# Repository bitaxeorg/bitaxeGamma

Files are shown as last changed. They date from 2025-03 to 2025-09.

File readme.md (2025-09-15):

```
Open Source is Intrinsic to Bitcoin
```
# The bitaxeGamma
bitaxe is a fully open source Bitcoin ASIC miner aimed at decentralizing mining. bitaxeGamma is the 5th major revision of the bitaxe that now includes the BM1370 ASIC from the Antminer S21 Pro

bitaxeUltra assembled

## Goals
- **Easy**: Just plug it in and mine Bitcoin over WiFi. No external computer needed.
- **Practical**: low cost, low noise, low power, low maintenance. You can run this at home.
- **ASIC Power**: High efficiency and hashrate, based on the latest and greatest Application Specific Integrated Circuits.
- **Versatile**: Mine to any StratumV1 pool, Lottery mine, Solo mine, Or hack it to do whatever you want.
- **Bitcoin Ethos**: Fully open source, permissionless and decentralized to support the worldwide freedom money.

## ASIC
At the heart of the bitaxeGamma is a BM1370 Bitcoin mining ASIC from the Antminer S21 Pro from Bitmain. It's not open source.

- Bitmain claims the BM1370 has 15 J/TH efficiency. We can get pretty close to that with the BitaxeGamma
- The Antminer S21 Pro has a nominal hashrate of 234 TH/s. There are 3 hashboards with 65 chips each, for a total of 195 chips. The bitaxeGamma has a single one of these chips. That means _about_ 1.2 TH/s per bitaxeGamma. Initial testing looks good!
- The BM1370 is brand new and isn't available individually yet. The best place to get these chips is right out of a S21 Pro.
- The BM1370 has a different footprint and pinout from the BM1368, BM1366, BM1397 and BM1387 in previous bitaxe.

## Current Status
- BitaxeGamma 600 is working well and has been released!
- In addition to higher hashrate, the Gamma also uses more power. Please pay attemtion to hash frequency and voltage settings as it's much easier to overheat, especially when using the stock heatsink and fan.
- BM1370 firmware support has been added to [esp-miner](https://github.com/skot/esp-miner)
- Be sure to check the [HW issues](https://github.com/skot/bitaxe/issues) for known bugs, reworks and errata.
- This is an _advanced_ build! You can do it, but if you're not looking for a project, it might be best to buy one pre-assembled from one of the [many sellers](https://bitaxe.org/legit.html). Check [Skot's method](assembly.md) of hand assembling PCBs.

## PCB Hardware
This repo contains all of the design files for the PCB. [KiCAD](https://www.kicad.org/) software is used. There is a BOM file for all of the components that get soldered to the PCB. 

- Order PCBs from your favorite PCB shop, like [JLCPCB](https://jlcpcb.com), [SeeedStudio](https://www.seeedstudio.com/fusion_pcb.html), or [PCBWay](https://www.pcbway.com)
    - Gerbers are in the `Manufacturing Files` dir. PCBs are 4-layer, 6mil trace/space and 0.3mm hole compatible. 1oz outer / 0.5oz inner layer thickness works well.
    - Make sure to order stencils too. These are the "paste" layers in the gerbers folder. one for top and one for bottom.
- All PCB parts except the ASIC are available from [DigiKey](https://www.digikey.com/en/products) and others. You can find Digikey part numbers on the DK tab of the BOM

## Extra Hardware
There are a few other hardware components that are needed for a complete bitaxe.

- **Heatsink**
	- [40x40mm heatsink and 5V fan](https://www.aliexpress.com/item/2251832861666365.html) from a random AliExpress seller. The fans are crap, but the heatsinks are good.  
- **Fan**
	- You **must** have active cooling on the bitaxe. The heatsink alone is not enough.
	- The Bitaxe has a connector for a 4pin, 5V PWM fan. 40mm square, 20mm thick fans work nicely with the suggested heatsink. Make sure to get a 5V fan! 12V spin, but slowly overheating your Bitaxe..
	- Upgrade your fan with the [Noctua NF-A4x10](https://noctua.at/en/nf-a4x10-5v-pwm) 5V 4-Pin fan for a much more pleasant experience.
- **Thermal compound**
	- Use a good quality thermal compound between the heatsink and ASIC. [Thermal Grizzly Kryonaut](https://www.amazon.com/Thermal-Grizzly-Kryonaut-Grease-Paste/dp/B011F7W3LU) has been known to work well.  
- **Display**
	- Supports 0.91" SSD1306-based I2C OLED Module. [Example Amazon seller](https://www.amazon.com/gp/product/B08ZY4YBHL). Make sure to get the male pins to interface with the Bitaxe PCB. 
- **Power Supply**
	- **5V DC Only!** Anything else will damage the Bitaxe. Be careful and double-check your power supply is 5V. Many other voltage power supplies use the same connector.
	- The power supply needs to supply in excess of 4A (20W) and not drop below 5V. Often times you have to use a power supply rated for 25-30W to get this!
 		- The [Meanwell GST60A05-P1J](https://www.digikey.com/en/products/detail/mean-well-usa-inc/GST60A05-P1J/7703709) at 30 Watts is the cadillac of 5V PSUs and is working well with the Gamma.  
	- The bitaxe uses a 5.5x2.1mm, center-positive barrel jack. 5.5x2.5mm plugs have been known to work.
- **Stand**
	- The PCB has corner mounting holes. You're going to want a stand to mount your Bitaxe. Many excellent 3D printed designs are available.

## Firmware
- The [ESP-Miner](https://github.com/skot/ESP-Miner) has initial support for the BM1370 ASIC. Improvements are ongoing.

### ESP32 Programming Requirements
- As of the bitaxeUltra, all ESP32 programming is done through a USB-C cable and connector on the bitaxe. See [ESP-Miner](https://github.com/skot/ESP-Miner) for more details.

## More Information
- Project page at [bitaxe.org](https://bitaxe.org)
- [Open Source Miners United](discord.gg/osmu) Discord chat
- [building.md](building.md) for PCB ordering tips
- [assembly.md](assembly.md) for assembly tips

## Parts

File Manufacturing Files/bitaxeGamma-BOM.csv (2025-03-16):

Qty | Reference | Value | PARTNO | DK | LCSC
1 | C6 | 4700pF | GRM155R71E472KA01D | 490-1309-1-ND
1 | C9 | 2200pF | GRM155R61H222KA01D | 490-8257-1-ND
1 | C10 | 4.7uF | GRM155R61A475MEAAD | 490-14306-1-ND
1 | C11 | 1000pF | CC0805KRX7R9BB102 | 311-1127-1-ND
1 | C13 | 100pF | 885012005013 | 732-7431-1-ND
1 | C50 | 470pF | CL05B471KB5NNNC | 1276-1566-1-ND
24 | C1 C5 C7 C21 C22 C23 C26 C27 C28 C30 C31 C32 C33 C34 C35 C36 C39 C40 C41 C42 C44 C45 C46 C48 | 1uF | EMK105BJ105MV-F | 587-5514-1-ND
3 | C14 C15 C16 | 22uF | GRM21BR61A226ME44L | 490-10746-1-ND
5 | C17 C18 C19 C20 C43 | 100uF | CL31A107MQHNNNE | 1276-1782-1-ND
2 | C2 C24 | 10uF | CL21A106KOQNNNE | 1276-1096-1-ND
3 | C3 C4 C51 | 47uF | CL32A476KOJNNNE | 1276-3376-1-ND
10 | C8 C12 C25 C29 C37 C38 C47 C49 C52 C53 | 0.1uF | CL05A104KO5NNNC | 1276-1234-1-ND
1 | J1 | 54-00164 | 54-00164 | 839-54-00164CT-ND | C431534
1 | J5 | USB_C_Receptacle_USB2.0 | USB4105-GF-A | 2073-USB4105-GF-ACT-ND
1 | J6 | Conn_01x04 | 0470531000 | WM4330-ND
1 | J7 | Conn_01x04
1 | L1 | 300nH | SLC1175-301MEC
1 | R1 | 8.25k | RC0402FR-078K25L | 311-8.25KLRCT-ND
1 | R5 | 14.7k | RC0402FR-0714K7L | YAG2984CT-ND
1 | R6 | 0 | RC0402JR-070RL | 311-0.0JRCT-ND
1 | R8 | 3.74k | RC0402FR-073K74L | 311-3.74KLRCT-ND
1 | R9 | 11.8k | RC0402FR-0711K8L | YAG2958CT-ND
1 | R10 | 68.1k | RC0402FR-0768K1L | YAG3213CT-ND
1 | R11 | 10 | RC0402FR-0710RL | 311-10.0LRCT-ND
1 | R12 | 1 | CSR1206FT1R00 | CSR1206FT1R00CT-ND
1 | R19 | 1k | RC0402FR-071KL | 311-1.00KLRCT-ND
1 | R21 | 20k | RC0402FR-0720KL | 311-20.0KLRCT-ND
1 | R24 | 5.6k | RC0402FR-135K6L | 13-RC0402FR-135K6LCT-ND
2 | R13 R14 | 49.9 | RC0402FR-0749R9L | 311-49.9LRCT-ND
4 | R15 R16 R17 R25 | 10k | RC0402JR-0710KL | 311-10KJRCT-ND
2 | R22 R23 | 100 | RC0402FR-07100RL | 311-100LRCT-ND
2 | SW1 SW2 | GT-TC029B-H025-L1N | CS1213AGF260 | 2449-CS1213AGF260CT-ND
1 | U2 | TPS546D24ARVFR | TPS546D24ARVFR | 296-TPS546D24ARVFRCT-ND
1 | U3 | RT9080-33GJ5 | RT9080-33GJ5 | 1028-1509-1-ND
1 | U4 | ESP32-S3-WROOM-1 | ESP32-S3-WROOM-1-N16R8 | 1965-ESP32-S3-WROOM-1-N16R8CT-ND
1 | U5 | MCP1824T-1202E/OT | MCP1824T-1202E/OT | MCP1824T-1202E/OTCT-ND
1 | U6 | MCP1824T-0802E | MCP1824T-0802E/OT | MCP1824T-0802E/OTCT-ND
1 | U7 | 25MHz | SX3M25.000E20F30THN |  | C5137262
1 | U8 | BM1370_mode1
1 | U9 | SN74AVC4T774 | SN74AVC4T774PWR | 296-24739-1-ND
1 | U10 | EMC2101 | EMC2101-R-ACZL-TR | EMC2101-R-ACZL-CT-ND

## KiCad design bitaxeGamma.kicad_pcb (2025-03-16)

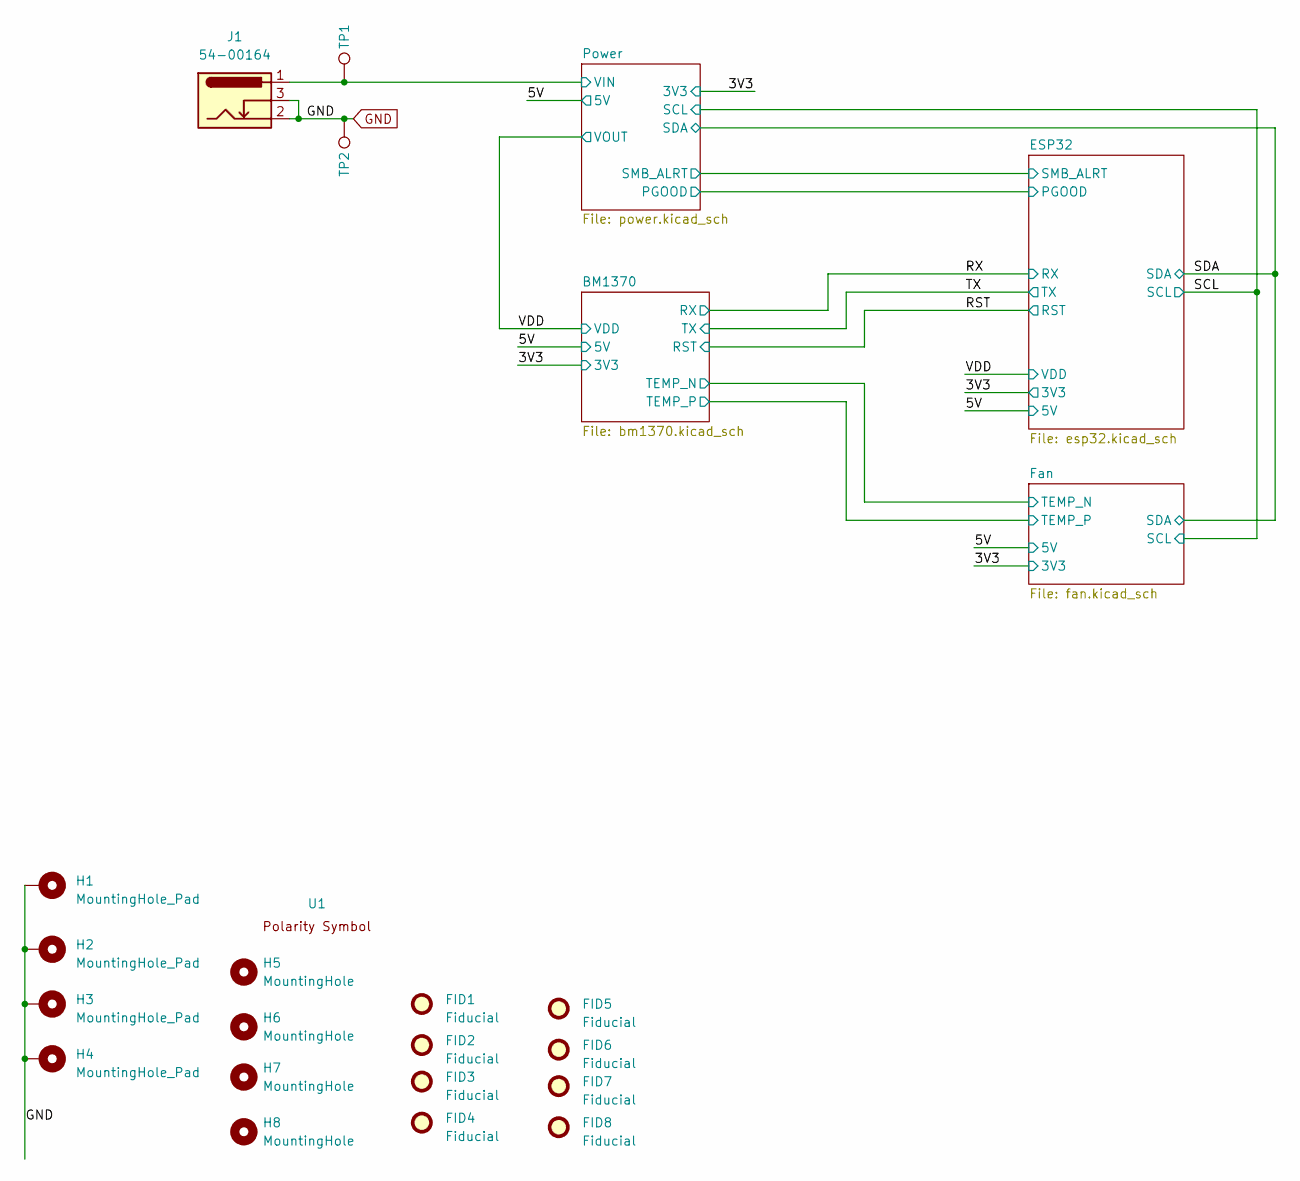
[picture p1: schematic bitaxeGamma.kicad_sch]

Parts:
FID1, FID2, FID3, FID4, FID5, FID6, FID7, FID8: Fiducial; Fiducial_1mm_Mask2mm
H1, H2, H3, H4: MountingHole_Pad; MountingHole_3mm_Pad_Via
H5, H6, H7, H8: MountingHole; MountingHole_3.5mm
J1: 54-00164; TENSILITY_54-00164; PARTNO 54-00164; LCSC C431534
TP1, TP2: TestPoint; TestPoint_Pad_D1.5mm
U1: polarity

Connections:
/5V: J1.1, TP1.1; also elsewhere on the board
GND: H1.1, H2.1, H3.1, H4.1, J1.2, J1.3, TP2.1; also elsewhere on the board

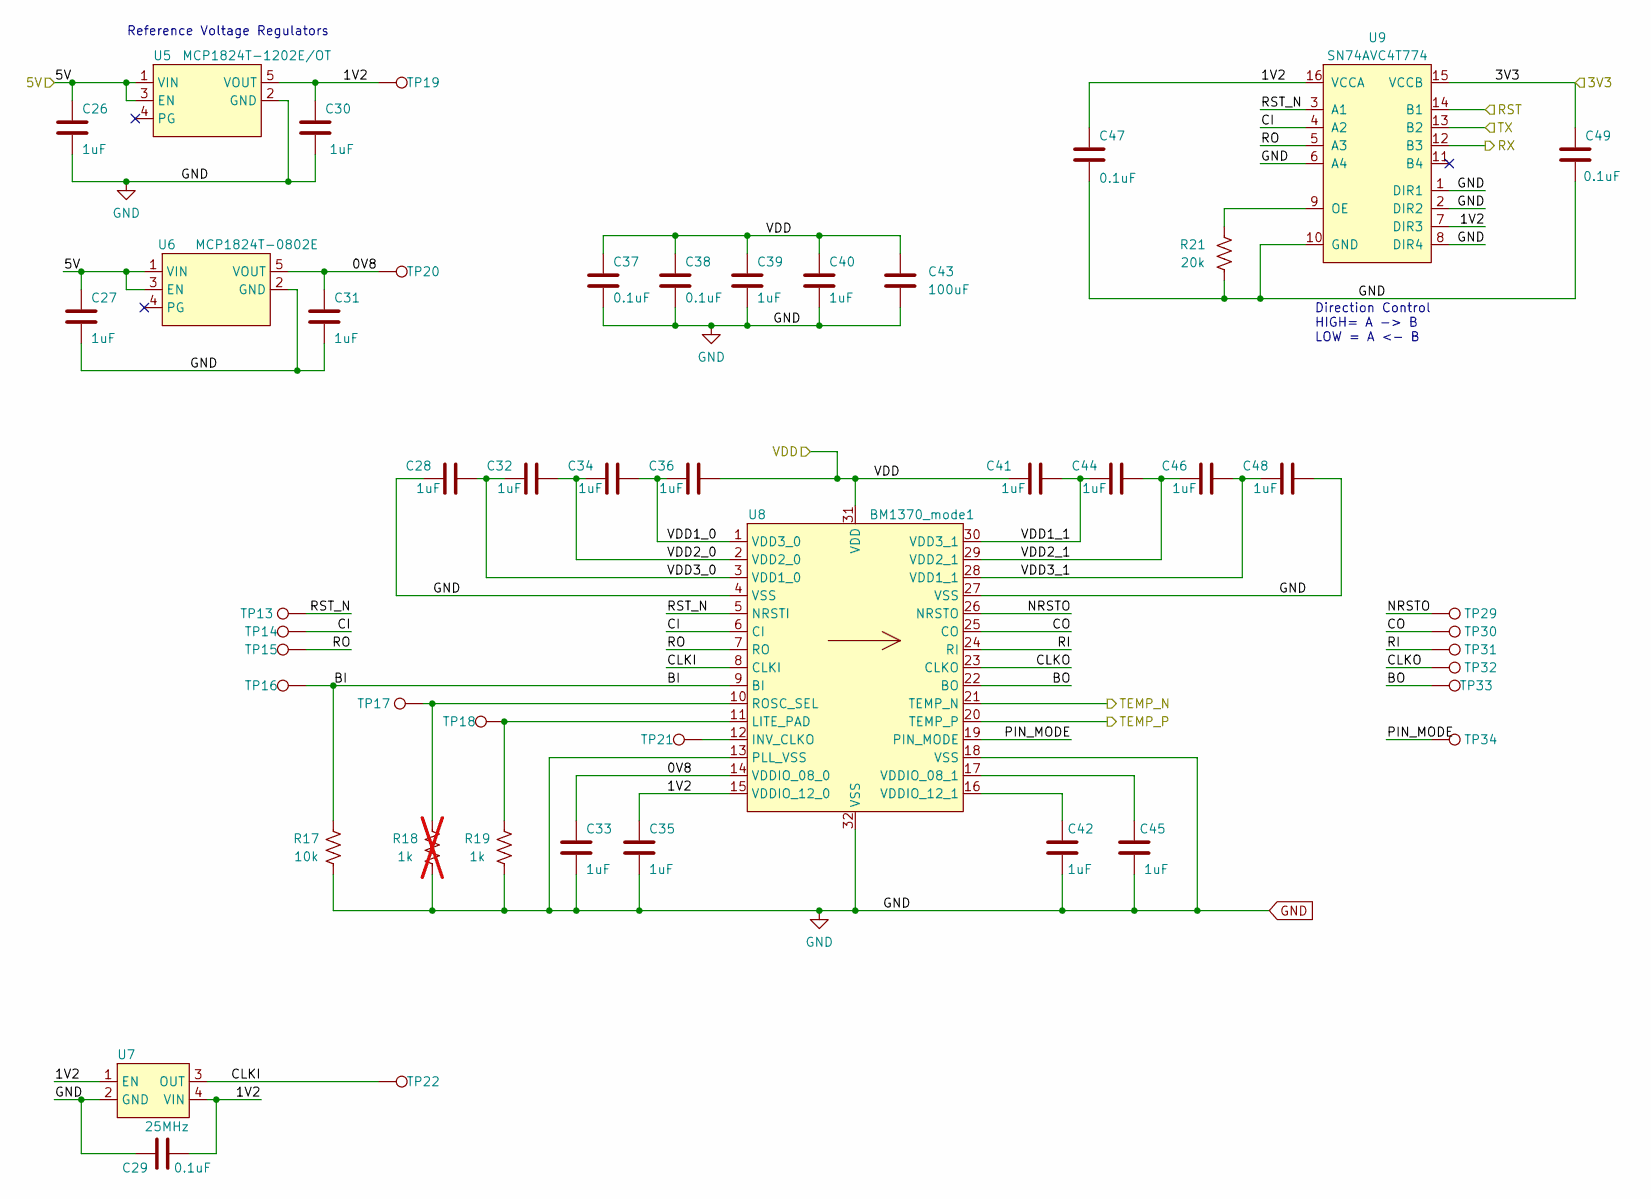
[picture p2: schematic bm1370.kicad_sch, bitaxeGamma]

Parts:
C26, C27, C28, C30, C31, C32, C33, C34, C35, C36, C39, C40, C41, C42, C44, C45, C46, C48: 1uF; C_0402_1005Metric; PARTNO EMK105BJ105MV-F
C29, C37, C38, C47, C49: 0.1uF; C_0402_1005Metric; PARTNO CL05A104KO5NNNC
C43: 100uF; C_1206_3216Metric; PARTNO CL31A107MQHNNNE
R17: 10k; R_0402_1005Metric; PARTNO RC0402JR-0710KL
R18: 1k; R_0402_1005Metric; PARTNO RC0402FR-071KL; not fitted
R19: 1k; R_0402_1005Metric; PARTNO RC0402FR-071KL
R21: 20k; R_0402_1005Metric; PARTNO RC0402FR-0720KL
TP13, TP14, TP15, TP16, TP17, TP18, TP19, TP20, TP21, TP22, TP29, TP30, TP31, TP32, TP33, TP34: TestPoint; TestPoint_Pad_D1.5mm
U5: MCP1824T-1202E/OT; SOT-23-5; PARTNO MCP1824T-1202E/OT
U6: MCP1824T-0802E; SOT-23-5; PARTNO MCP1824T-0802E/OT
U7: 25MHz; SMD3225-4P; PARTNO SX3M25.000E20F30THN; LCSC C5137262
U8: BM1370_mode1; BM1370
U9: SN74AVC4T774; TSSOP-16_4.4x5mm_P0.65mm; PARTNO SN74AVC4T774PWR

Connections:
/3V3: C49.1, U9.15 (VCCB); also elsewhere on the board
/5V: C26.1, C27.1, U5.1 (VIN), U5.3 (EN), U6.1 (VIN), U6.3 (EN); also elsewhere on the board
/BM1370/0V8: C31.1, C33.1, TP20.1, U6.5 (VOUT), U8.14 (VDDIO_08_0)
/BM1370/1V2: C29.2, C30.1, C35.1, C47.1, TP19.1, U5.5 (VOUT), U7.1 (EN), U7.4 (VIN), U8.15 (VDDIO_12_0), U9.7 (DIR3), U9.16 (VCCA)
/BM1370/BI: R17.2, TP16.1, U8.9 (BI)
/BM1370/BO: TP33.1, U8.22 (BO)
/BM1370/CI: TP14.1, U8.6 (CI), U9.4 (A2)
/BM1370/CLKI: TP22.1, U7.3 (OUT), U8.8 (CLKI)
/BM1370/CLKO: TP32.1, U8.23 (CLKO)
/BM1370/CO: TP30.1, U8.25 (CO)
/BM1370/NRSTO: TP29.1, U8.26 (NRSTO)
/BM1370/PIN_MODE: TP34.1, U8.19 (PIN_MODE)
/BM1370/RI: TP31.1, U8.24 (RI)
/BM1370/RO: TP15.1, U8.7 (RO), U9.5 (A3)
/BM1370/RST_N: TP13.1, U8.5 (NRSTI), U9.3 (A1)
/BM1370/VDD1_0: C34.2, C36.1, U8.1 (VDD3_0)
/BM1370/VDD1_1: C41.2, C44.1, U8.30 (VDD3_1)
/BM1370/VDD2_0: C32.2, C34.1, U8.2 (VDD2_0)
/BM1370/VDD2_1: C44.2, C46.1, U8.29 (VDD2_1)
/BM1370/VDD3_0: C28.2, C32.1, U8.3 (VDD1_0)
/BM1370/VDD3_1: C46.2, C48.1, U8.28 (VDD1_1)
/Fan/TEMP_N: U8.21 (TEMP_N); also elsewhere on the board
/Fan/TEMP_P: U8.20 (TEMP_P); also elsewhere on the board
/RST: U9.14 (B1); also elsewhere on the board
/RX: U9.12 (B3); also elsewhere on the board
/TX: U9.13 (B2); also elsewhere on the board
/VDD: C36.2, C37.1, C38.1, C39.1, C40.1, C41.1, C43.1, U8.31 (VDD); also elsewhere on the board
GND: C26.2, C27.2, C28.1, C29.1, C30.2, C31.2, C33.2, C35.2, C37.2, C38.2, C39.2, C40.2, C42.2, C43.2, C45.2, C47.2, C48.2, C49.2, R17.1, R18.1, R19.1, R21.1, U5.2 (GND), U6.2 (GND), U7.2 (GND), U8.4 (VSS), U8.13 (PLL_VSS), U8.18 (VSS), U8.27 (VSS), U8.32 (VSS), U9.1 (DIR1), U9.2 (DIR2), U9.6 (A4), U9.8 (DIR4), U9.10 (GND); also elsewhere on the board
unnamed: TP21.1, U8.12 (INV_CLKO)
unnamed: R19.2, TP18.1, U8.11 (LITE_PAD)
unnamed: R18.2, TP17.1, U8.10 (ROSC_SEL)
unnamed: C45.1, U8.17 (VDDIO_08_1)
unnamed: C42.1, U8.16 (VDDIO_12_1)
unnamed: R21.2, U9.9 (OE)

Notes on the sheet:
Reference Voltage Regulators
Direction Control HIGH= A -> B LOW = A <- B

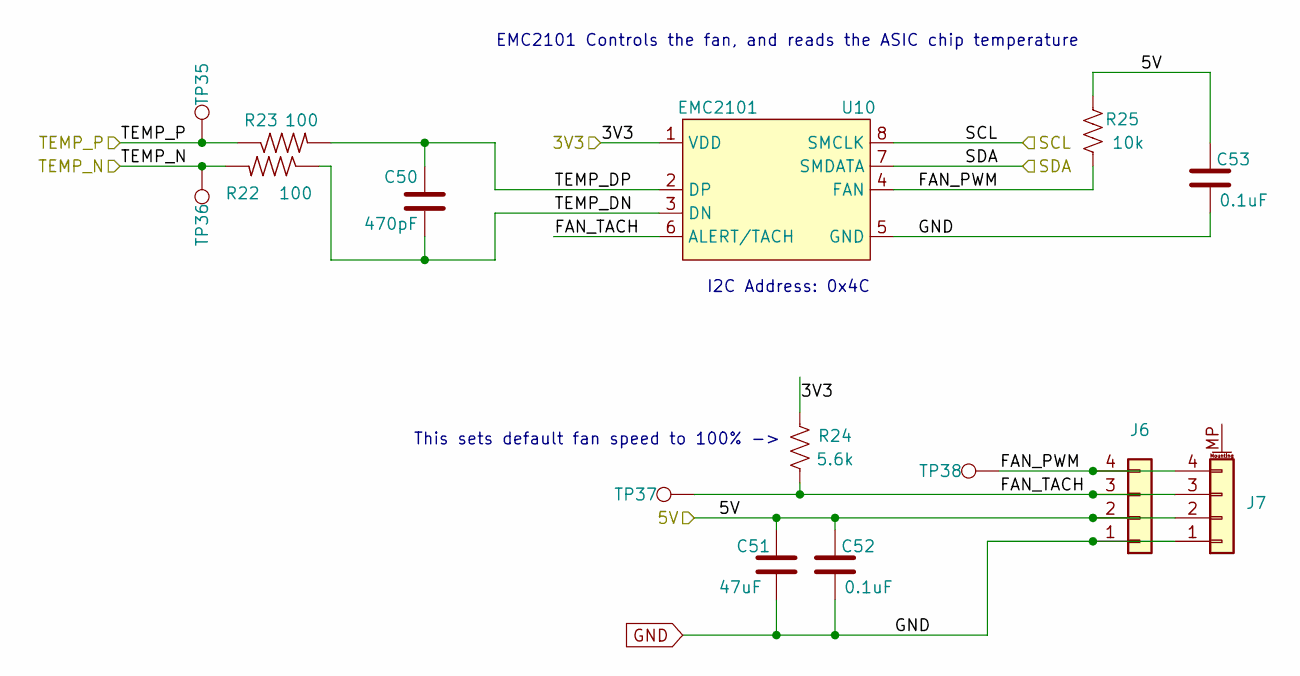
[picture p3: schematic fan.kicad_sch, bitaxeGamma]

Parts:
C50: 470pF; C_0402_1005Metric; PARTNO CL05B471KB5NNNC
C51: 47uF; C_1210_3225Metric; PARTNO CL32A476KOJNNNE
C52, C53: 0.1uF; C_0402_1005Metric; PARTNO CL05A104KO5NNNC
J6: Conn_01x04; 470531000; PARTNO 0470531000
J7: Conn_01x04; JST_SH_BM04B-SRSS-TB_1x04-1MP_P1.00mm_Vertical
R22, R23: 100; R_0402_1005Metric; PARTNO RC0402FR-07100RL
R24: 5.6k; R_0402_1005Metric; PARTNO RC0402FR-135K6L
R25: 10k; R_0402_1005Metric; PARTNO RC0402JR-0710KL
TP35, TP36, TP37, TP38: TestPoint; TestPoint_Pad_D1.5mm
U10: EMC2101; TSSOP-8_3x3mm_P0.65mm; PARTNO EMC2101-R-ACZL-TR

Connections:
/3V3: R24.2, U10.1 (VDD); also elsewhere on the board
/5V: C51.1, C52.1, C53.1, J6.2, J7.2, R25.2; also elsewhere on the board
/Fan/FAN_PWM: J6.4, J7.4, R25.1, TP38.1, U10.4 (FAN)
/Fan/FAN_TACH: J6.3, J7.3, R24.1, TP37.1, U10.6 (ALERT/TACH)
/Fan/TEMP_DN: C50.2, R22.1, U10.3 (DN)
/Fan/TEMP_DP: C50.1, R23.2, U10.2 (DP)
/Fan/TEMP_N: R22.2, TP36.1; also elsewhere on the board
/Fan/TEMP_P: R23.1, TP35.1; also elsewhere on the board
/SCL: U10.8 (SMCLK); also elsewhere on the board
/SDA: U10.7 (SMDATA); also elsewhere on the board
GND: C51.2, C52.2, C53.2, J6.1, J7.1, U10.5 (GND); also elsewhere on the board

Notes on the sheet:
EMC2101 Controls the fan, and reads the ASIC chip temperature
This sets default fan speed to 100% ->
I2C Address: 0x4C

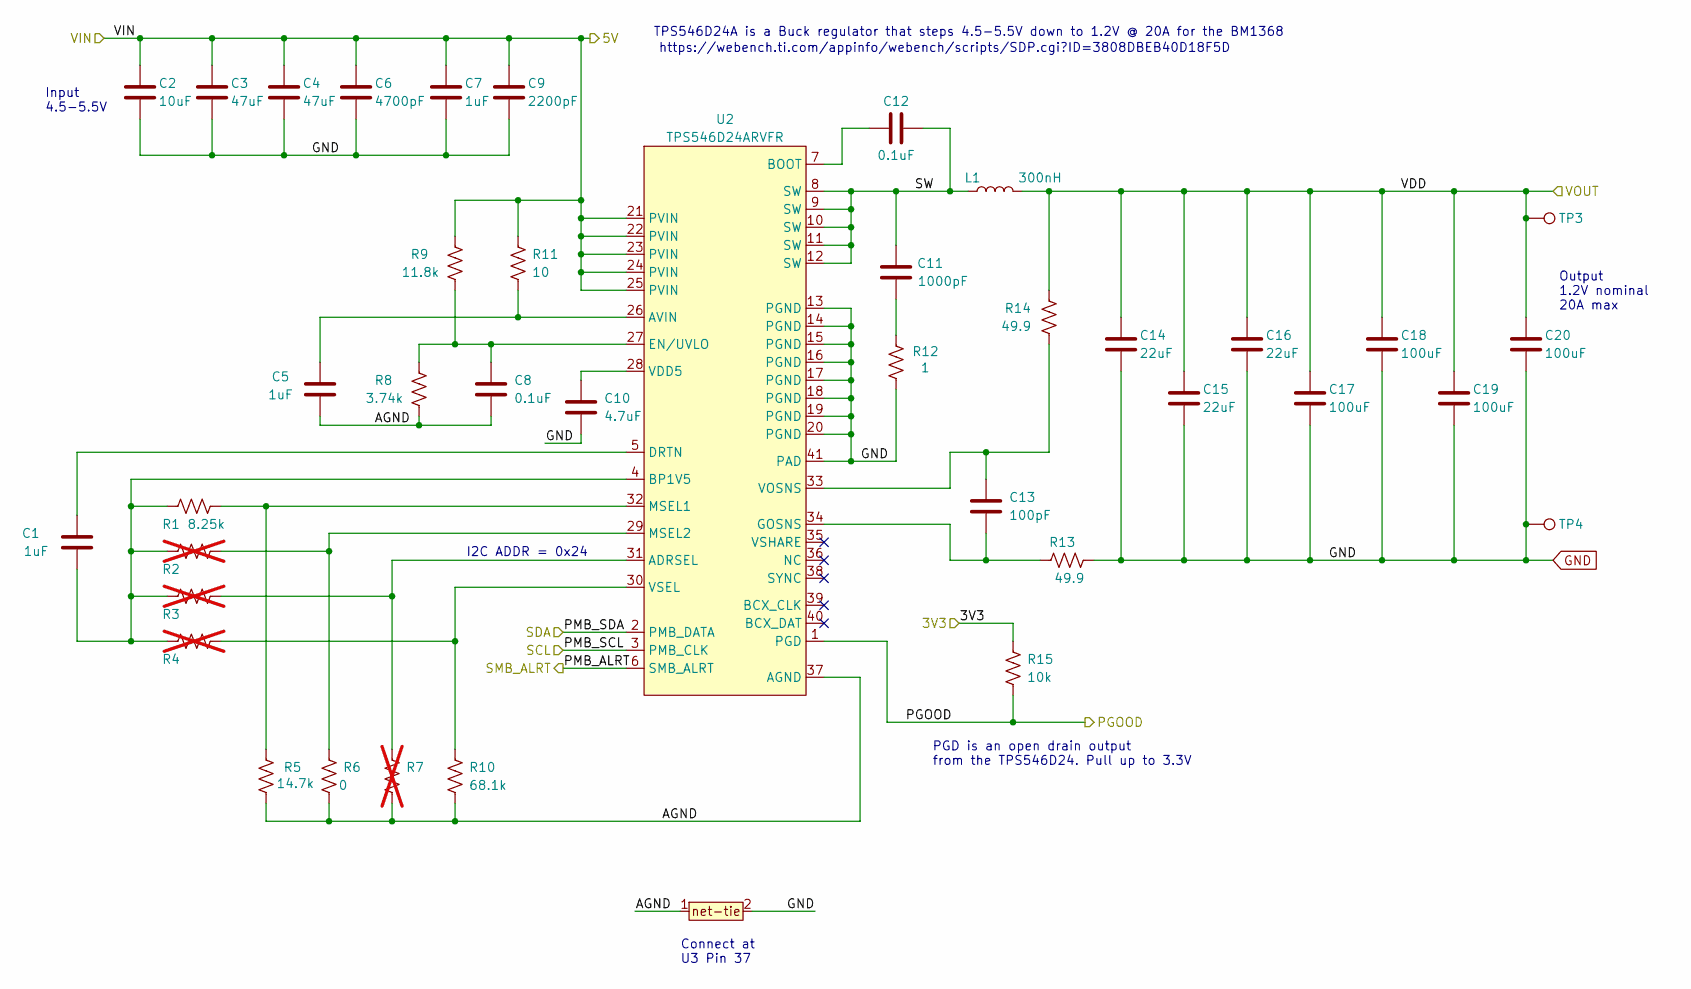
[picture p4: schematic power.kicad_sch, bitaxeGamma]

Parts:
C1, C5, C7: 1uF; C_0402_1005Metric; PARTNO EMK105BJ105MV-F
C2: 10uF; C_0805_2012Metric; PARTNO CL21A106KOQNNNE
C3, C4: 47uF; C_1210_3225Metric; PARTNO CL32A476KOJNNNE
C6: 4700pF; C_0402_1005Metric; PARTNO GRM155R71E472KA01D
C8, C12: 0.1uF; C_0402_1005Metric; PARTNO CL05A104KO5NNNC
C9: 2200pF; C_0402_1005Metric; PARTNO GRM155R61H222KA01D
C10: 4.7uF; C_0402_1005Metric; PARTNO GRM155R61A475MEAAD
C11: 1000pF; C_0805_2012Metric; PARTNO CC0805KRX7R9BB102
C13: 100pF; C_0402_1005Metric; PARTNO 885012005013
C14, C15, C16: 22uF; C_0805_2012Metric; PARTNO GRM21BR61A226ME44L
C17, C18, C19, C20: 100uF; C_1206_3216Metric; PARTNO CL31A107MQHNNNE
L1: 300nH; SLC1175-271MEC_COC; PARTNO SLC1175-301MEC; Mouser 994-SLC1175-271MEC
R1: 8.25k; R_0402_1005Metric; PARTNO RC0402FR-078K25L
R2, R3, R4, R7: R_0402_1005Metric; not fitted
R5: 14.7k; R_0402_1005Metric; PARTNO RC0402FR-0714K7L
R6: 0; R_0402_1005Metric; PARTNO RC0402JR-070RL
R8: 3.74k; R_0402_1005Metric; PARTNO RC0402FR-073K74L
R9: 11.8k; R_0402_1005Metric; PARTNO RC0402FR-0711K8L
R10: 68.1k; R_0402_1005Metric; PARTNO RC0402FR-0768K1L
R11: 10; R_0402_1005Metric; PARTNO RC0402FR-0710RL
R12: 1; R_1206_3216Metric; PARTNO CSR1206FT1R00
R13, R14: 49.9; R_0402_1005Metric; PARTNO RC0402FR-0749R9L
R15: 10k; R_0402_1005Metric; PARTNO RC0402JR-0710KL
T1: net-tie; NetTie-0.25mm
TP3, TP4: TestPoint; TestPoint_Pad_D1.5mm
U2: TPS546D24ARVFR; LQFN40-CLIP; PARTNO TPS546D24ARVFR

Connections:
/3V3: R15.2; also elsewhere on the board
/5V: C2.1, C3.1, C4.1, C6.1, C7.1, C9.1, R9.1, R11.1, U2.21 (PVIN), U2.22 (PVIN), U2.23 (PVIN), U2.24 (PVIN), U2.25 (PVIN); also elsewhere on the board
/Power/AGND: C5.1, C8.2, R5.1, R6.2, R7.2, R8.2, R10.2, T1.1, U2.37 (AGND)
/Power/PGOOD: R15.1, U2.1 (PGD); also elsewhere on the board
/Power/PMB_ALRT: U2.6 (SMB_ALRT); also elsewhere on the board
/Power/SW: C11.2, C12.2, L1.1, U2.8 (SW), U2.9 (SW), U2.10 (SW), U2.11 (SW), U2.12 (SW)
/SCL: U2.3 (PMB_CLK); also elsewhere on the board
/SDA: U2.2 (PMB_DATA); also elsewhere on the board
/VDD: C14.1, C15.1, C16.1, C17.1, C18.1, C19.1, C20.1, L1.2, R14.1, TP3.1; also elsewhere on the board
GND: C2.2, C3.2, C4.2, C6.2, C7.2, C9.2, C10.2, C14.2, C15.2, C16.2, C17.2, C18.2, C19.2, C20.2, R12.1, R13.2, T1.2, TP4.1, U2.13 (PGND), U2.14 (PGND), U2.15 (PGND), U2.16 (PGND), U2.17 (PGND), U2.18 (PGND), U2.19 (PGND), U2.20 (PGND), U2.41 (PAD); also elsewhere on the board
unnamed: C11.1, R12.2
unnamed: R3.2, R7.1, U2.31 (ADRSEL)
unnamed: C5.2, R11.2, U2.26 (AVIN)
unnamed: C12.1, U2.7 (BOOT)
unnamed: C1.2, R1.1, R2.1, R3.1, R4.1, U2.4 (BP1V5)
unnamed: C1.1, U2.5 (DRTN)
unnamed: C8.1, R8.1, R9.2, U2.27 (EN/UVLO)
unnamed: C13.2, R13.1, U2.34 (GOSNS)
unnamed: R1.2, R5.2, U2.32 (MSEL1)
unnamed: R2.2, R6.1, U2.29 (MSEL2)
unnamed: C10.1, U2.28 (VDD5)
unnamed: C13.1, R14.2, U2.33 (VOSNS)
unnamed: R4.2, R10.1, U2.30 (VSEL)

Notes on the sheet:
TPS546D24A is a Buck regulator that steps 4.5-5.5V down to 1.2V @ 20A for the BM1368
https://webench.ti.com/appinfo/webench/scripts/SDP.cgi?ID=3808DBEB40D18F5D
Input 4.5-5.5V
PGD is an open drain output from the TPS546D24. Pull up to 3.3V
I2C ADDR = 0x24
Output 1.2V nominal 20A max
Connect at U3 Pin 37

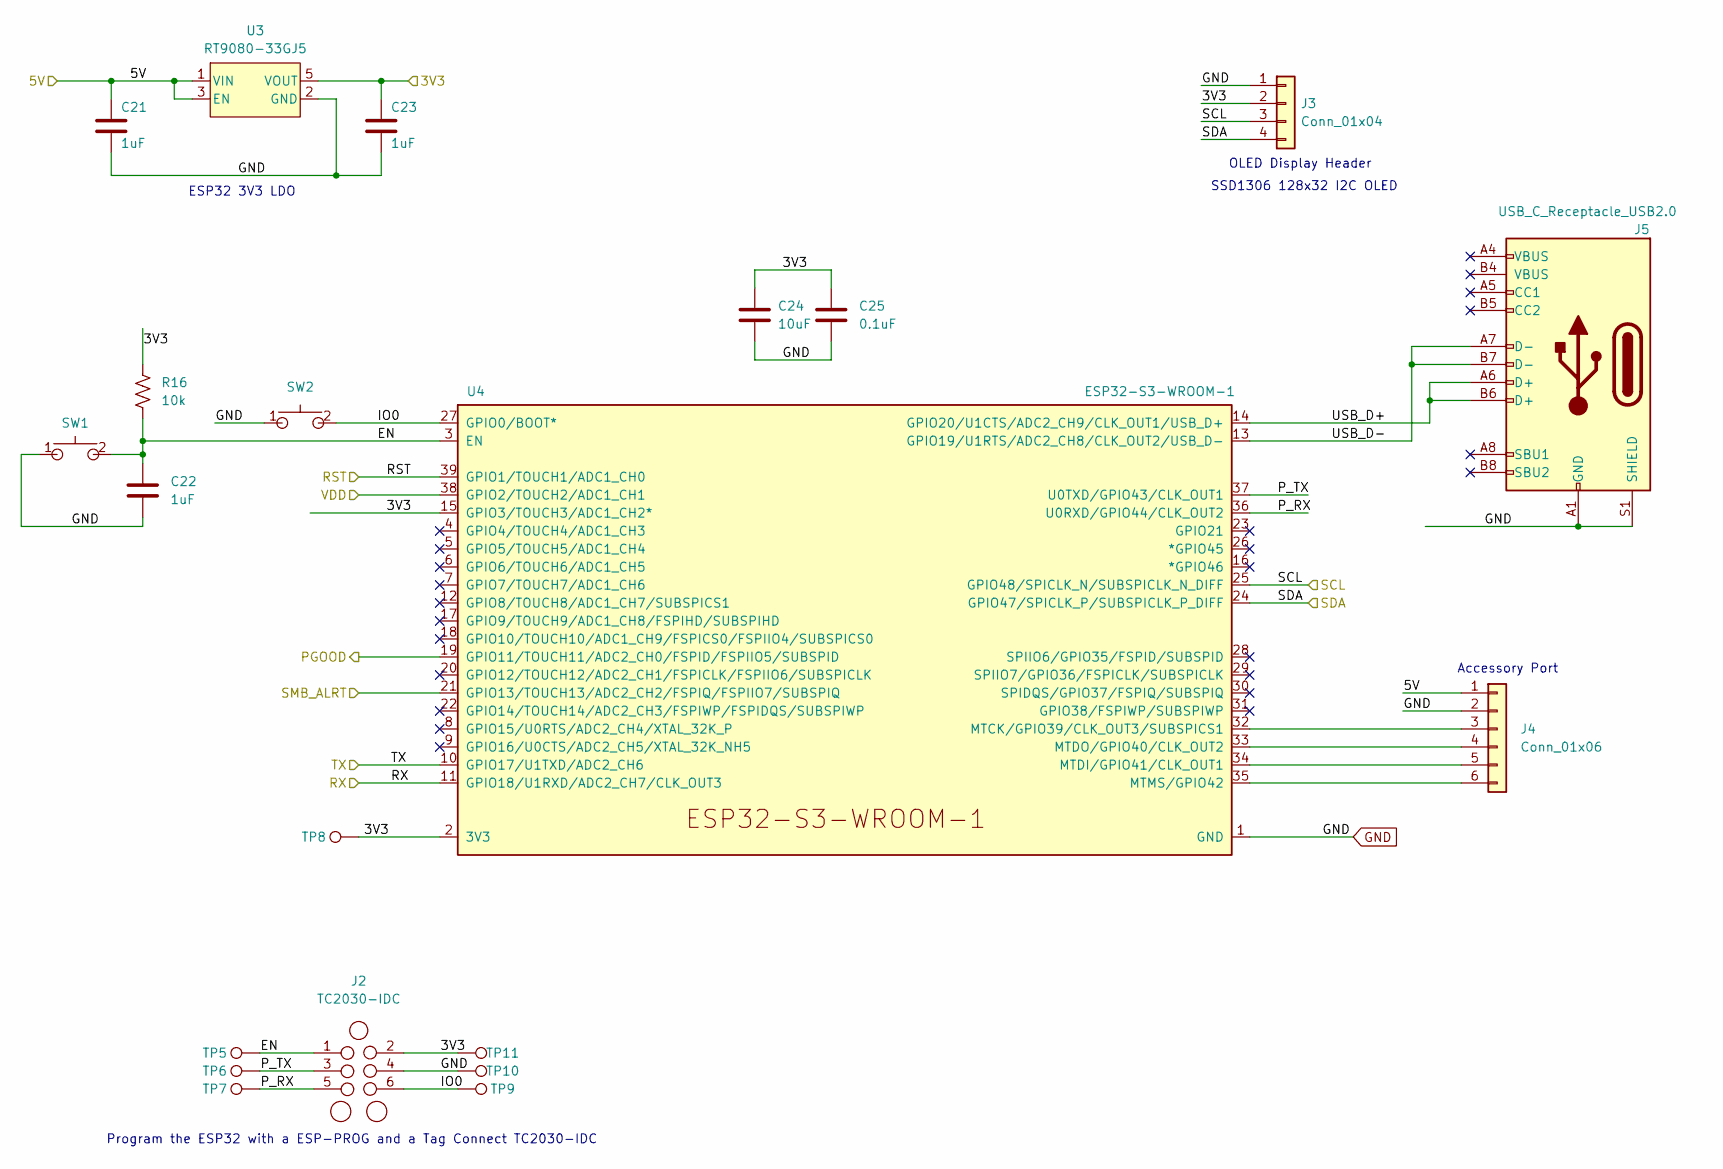
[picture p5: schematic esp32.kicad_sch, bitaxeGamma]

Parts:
C21, C22, C23: 1uF; C_0402_1005Metric; PARTNO EMK105BJ105MV-F
C24: 10uF; C_0805_2012Metric; PARTNO CL21A106KOQNNNE
C25: 0.1uF; C_0402_1005Metric; PARTNO CL05A104KO5NNNC
J2: TC2030-IDC; Tag-Connect_TC2030-IDC-NL_2x03_P1.27mm_Vertical
J3: Conn_01x04; PinHeader_1x04_P2.54mm_Vertical_shifted
J4: Conn_01x06; PinHeader_1x06_P2.54mm_Vertical
J5: USB_C_Receptacle_USB2.0; USB_C_Receptacle_GCT_USB4105-xx-A; PARTNO USB4105-GF-A
R16: 10k; R_0402_1005Metric; PARTNO RC0402JR-0710KL
SW1, SW2: GT-TC029B-H025-L1N; SW_CS1213AGF260_CRS; PARTNO CS1213AGF260
TP5, TP6, TP7, TP8, TP9, TP10, TP11: TestPoint; TestPoint_Pad_D1.5mm
U3: RT9080-33GJ5; PARTNO RT9080-33GJ5
U4: ESP32-S3-WROOM-1; PARTNO ESP32-S3-WROOM-1-N16R8

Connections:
/3V3: C23.1, C24.1, C25.1, J2.2, J3.2, R16.1, TP8.1, TP11.1, U3.5 (VOUT), U4.2 (3V3), U4.15 (GPIO3/TOUCH3/ADC1_CH2*); also elsewhere on the board
/5V: C21.1, J4.1, U3.1 (VIN), U3.3 (EN); also elsewhere on the board
/ESP32/EN: C22.1, J2.1, R16.2, SW1.2, TP5.1, U4.3 (EN)
/ESP32/IO0: J2.6, SW2.2, TP9.1, U4.27 (GPIO0/BOOT*)
/ESP32/P_RX: J2.5, TP7.1, U4.36 (U0RXD/GPIO44/CLK_OUT2)
/ESP32/P_TX: J2.3, TP6.1, U4.37 (U0TXD/GPIO43/CLK_OUT1)
/ESP32/USB_D+: J5.A6 (D+), J5.B6 (D+), U4.14 (GPIO20/U1CTS/ADC2_CH9/CLK_OUT1/USB_D+)
/ESP32/USB_D-: J5.A7 (D-), J5.B7 (D-), U4.13 (GPIO19/U1RTS/ADC2_CH8/CLK_OUT2/USB_D-)
/Power/PGOOD: U4.19 (GPIO11/TOUCH11/ADC2_CH0/FSPID/FSPIIO5/S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); also elsewhere on the board
/Power/PMB_ALRT: U4.21 (GPIO13/TOUCH13/ADC2_CH2/FSPIQ/FSPIIO7/S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); also elsewhere on the board
/RST: U4.39 (GPIO1/TOUCH1/ADC1_CH0); also elsewhere on the board
/RX: U4.11 (GPIO18/U1RXD/ADC2_CH7/CLK_OUT3); also elsewhere on the board
/SCL: J3.3, U4.25 (GPIO48/SPICLK_N/SUBSPICLK_N_DIFF); also elsewhere on the board
/SDA: J3.4, U4.24 (GPIO47/SPICLK_P/SUBSPICLK_P_DIFF); also elsewhere on the board
/TX: U4.10 (GPIO17/U1TXD/ADC2_CH6); also elsewhere on the board
/VDD: U4.38 (GPIO2/TOUCH2/ADC1_CH1); also elsewhere on the board
GND: C21.2, C22.2, C23.2, C24.2, C25.2, J2.4, J3.1, J4.2, J5.A1 (GND), J5.B1 (GND), J5.S1 (SHIELD), SW1.1, SW2.1, TP10.1, U3.2 (GND), U4.1 (GND), U4.40 (GND), U4.41 (GND); also elsewhere on the board
unnamed: J4.3, U4.32 (MTCK/GPIO39/CLK_OUT3/SUBSPICS1)
unnamed: J4.4, U4.33 (MTDO/GPIO40/CLK_OUT2)
unnamed: J4.5, U4.34 (MTDI/GPIO41/CLK_OUT1)
unnamed: J4.6, U4.35 (MTMS/GPIO42)

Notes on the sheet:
Accessory Port
ESP32 3V3 LDO
Program the ESP32 with a ESP-PROG and a Tag Connect TC2030-IDC
SSD1306 128x32 I2C OLED
OLED Display Header

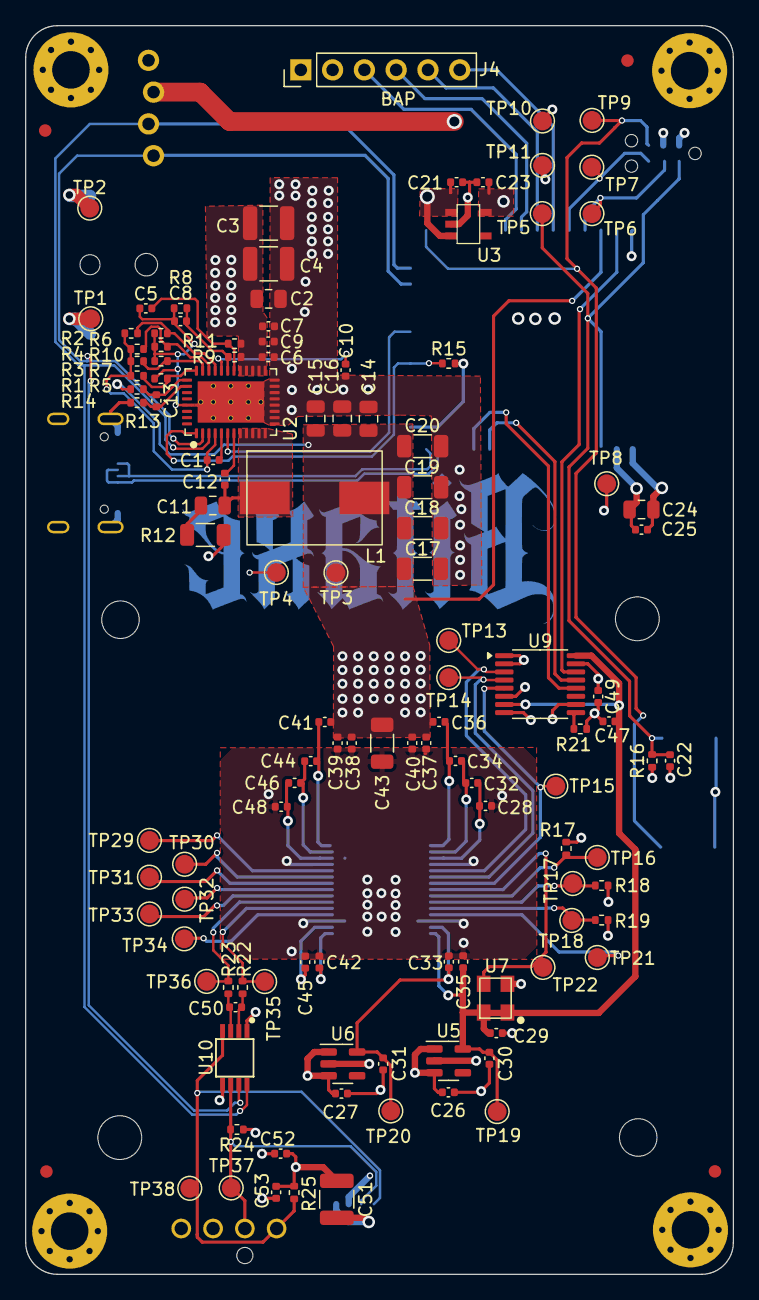
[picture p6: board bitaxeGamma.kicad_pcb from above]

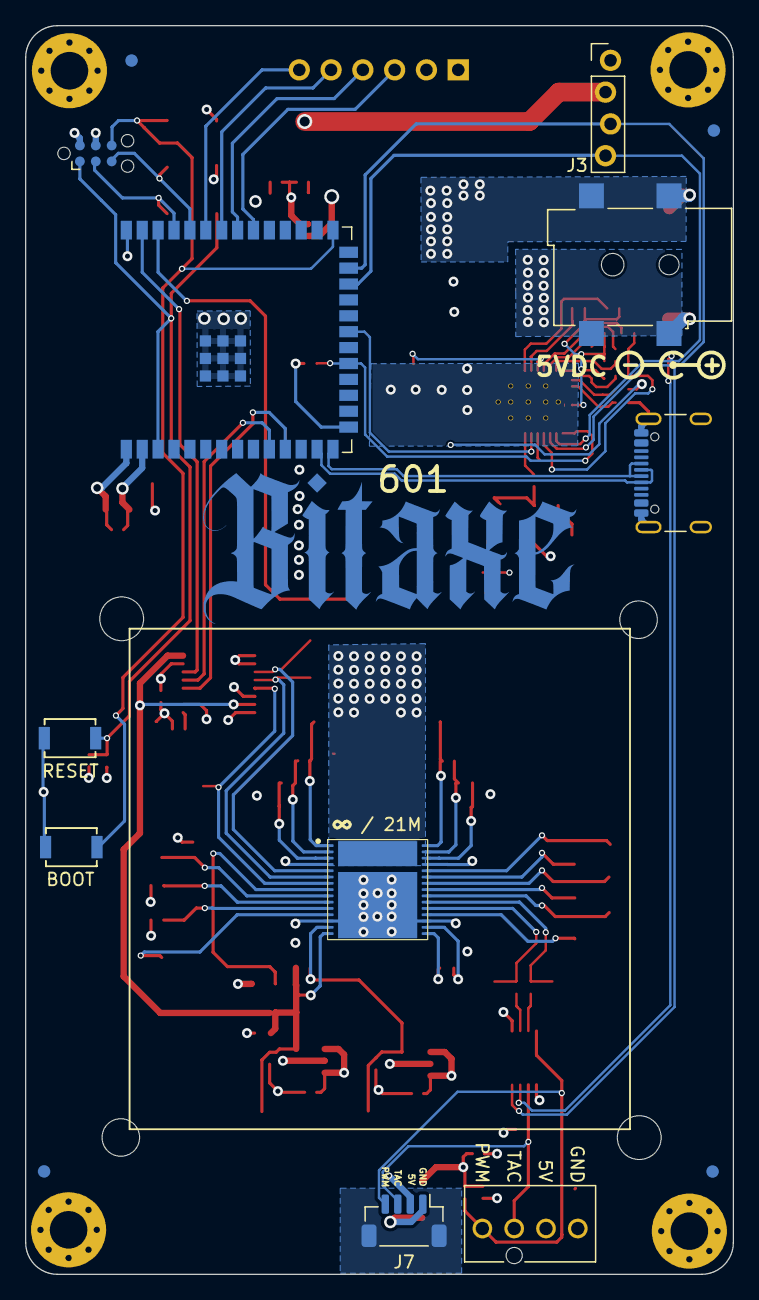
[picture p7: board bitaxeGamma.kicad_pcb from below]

Board: 4 copper layers, 56.5 x 99.8 mm, 145 parts (15 on the bottom side), 67 nets.

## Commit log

2025-01-21 added alternate part number for the 25MHz ASIC oscillator
    [bm1370.kicad_sch]
2025-01-25 Cleaned up zones, increased vdd trace width
    [bitaxeGamma.kicad_pcb]
2025-01-25 mounting holes to 3mm
    [bitaxeGamma.kicad_pcb, bitaxeGamma.kicad_sch]
2025-01-25 lots of misc
    [bitaxeGamma.kicad_pcb, bm1370.kicad_sch, esp32.kicad_sch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]
2025-01-25 more input vias
    [bitaxeGamma.kicad_pcb]
2025-01-25 tps546 is smd
    [bitaxeGamma.kicad_pcb]
2025-01-25 refill zones
    [bitaxeGamma.kicad_pcb]
2025-01-28 inductor change
    [bitaxeGamma-B_Cu.gbr, bitaxeGamma-B_Mask.gbr, bitaxeGamma-B_Paste.gbr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]
2025-03-05 Fix BM17 footprint
2025-03-06 update footprint
    [bitaxeGamma.kicad_pcb]
2025-03-16 update to KiCad v9
    [bitaxeGamma.kicad_pcb, bitaxeGamma.kicad_sch, bm1370.kicad_sch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]
2025-03-16 remove unused DNP column from BOM
    [bitaxeGamma-BOM.csv]
2025-09-15 Fixed KiCAD link
    Fixed KiCAD link to kicad.org
